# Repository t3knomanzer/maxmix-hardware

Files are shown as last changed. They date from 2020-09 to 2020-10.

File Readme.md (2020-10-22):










## Overview
**Maxmix** is an open-source volume mixer that allows you to control the volume applications from an external custom controller.  
It was originally designed to allow to quickly adjust the volume of a game and an external voice chat application like Discord quckly, but it can do so much more...  
You can find out more about the system in the [project website](https://www.maxmixproject.com).

This repository contains the designs to build the official hardware.

## Contributing
Most files on this repository are binary and do not allow for changes to be merged.  
To prevent changes being overwritten, we  use [LFS with locking](https://github.com/git-lfs/git-lfs/wiki/File-Locking).  

Before you start working on a file, you need to lock it. Locks are exclusive so only one user can lock a file at a time. Locking the file will also make it
writeable locally and allow you to make changes to it.

Here are a few useful commands:

Lock a file
```
$ git lfs lock images/foo.jpg
Locked images/foo.jpg
```

Unlock a file
```
$ git lfs unlock images/foo.jpg
$ git lfs unlock --id=456
```

View locked files
```
$ git lfs locks
images/bar.jpg  jane   ID:123
images/foo.jpg  alice  ID:456
```

Typical workflow
```
$ git lfs lock images/foo.jpg
$ git commit images/foo.jpg -m "My changes"
$ git lfs unlock images/foo.jpg
$ git push
```

## Community
You can join these groups and chats to discuss your-project related questions:

[Website](https://maxmixproject.com)  
[Twitter](https://www.twitter.com/maxmixproject)  
[Reddit](https://www.reddit.com/r/maxmixproject)    
[Discord](https://discord.gg/TmvvgCw)  
[Github](https://www.github.com/t3knomanzer/maxmix-software)  
[Thingiverse](https://www.thingiverse.com/thing:4343186)  
[Prusaprinters](https://www.prusaprinters.org/prints/31336-maxmix)  
[Buy](https://www.amazon.com/dp/B08LMQXTZ3)  
[Donate](https://www.paypal.com/cgi-bin/webscr?cmd=_donations&business=SQS6XJZBCBZA8&currency_code=USD&source=url)

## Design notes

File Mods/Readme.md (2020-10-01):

This folder will contain mods made for the Maxmix device.

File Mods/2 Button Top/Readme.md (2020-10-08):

## Tactile button mod

Uses KY-004 buttons from Ali/Amazon

 - Amazon - https://www.amazon.com/gp/product/B0786BDFT5/ - Soldering
   was poor, needed to be fixed before using.
   
 - Aliexpress - https://www.aliexpress.com/item/4000210666955.html

Use software & firmware located in this folder or source is here - https://github.com/t3knomanzer/maxmix-software/tree/mod-buttons

Currently presses F13 and F14, buttons need to be wired to ground and D10/D11. D8 and D9 are pulled low in this firmware and can be used in place of ground.

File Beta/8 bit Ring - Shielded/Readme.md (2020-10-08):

Shielded LED housing for the project standard 8 bit ring.

Diffuser = Visible, should be printed in a transparent or translucent material. White, Clear, Light Colors...

Shield = Blocks light between cells and from exiting housing, should be printed in a non-translucent material. Black, Dark Colors...

Bracket = Blocks light from exiting bottom and side of housing, should be printed in a non-translucent material. Black, Dark Colors...

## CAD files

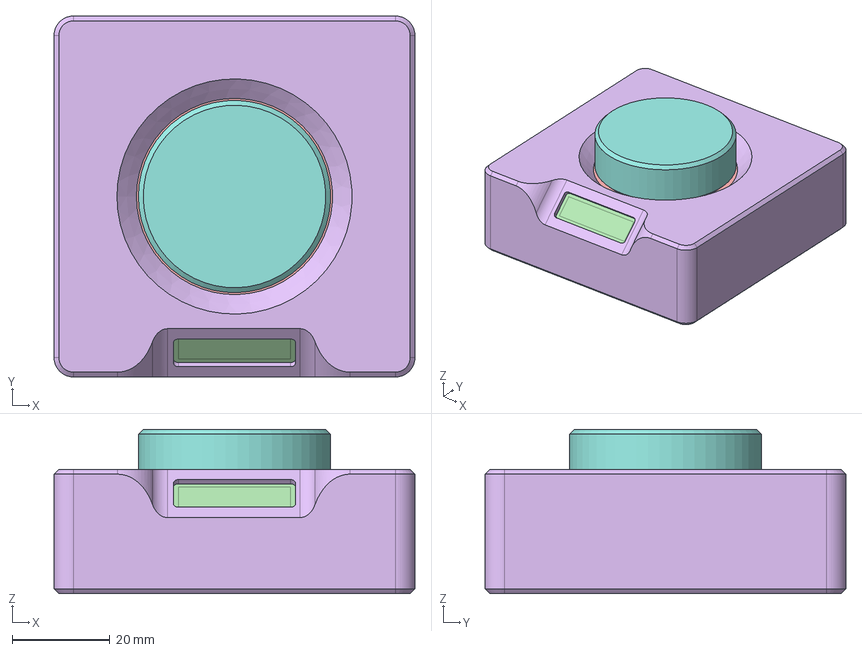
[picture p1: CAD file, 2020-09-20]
Base/R96/Maxmix_Base_R96.step
74.0 x 74.0 x 33.7 mm
Arduino
Rotary
OLED
Top
Bottom
Knob
Tabs
PowerBus
LightRingBracket
LightRing

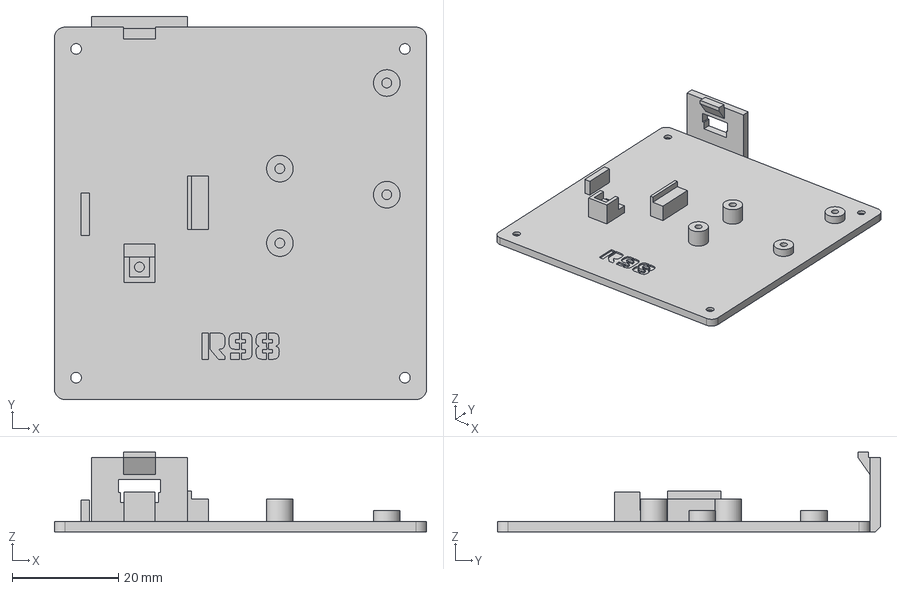
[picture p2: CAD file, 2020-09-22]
Base/R98/Step/Maxmix_Base_Bottom_14mm_R98.step
70.0 x 72.0 x 15.0 mm

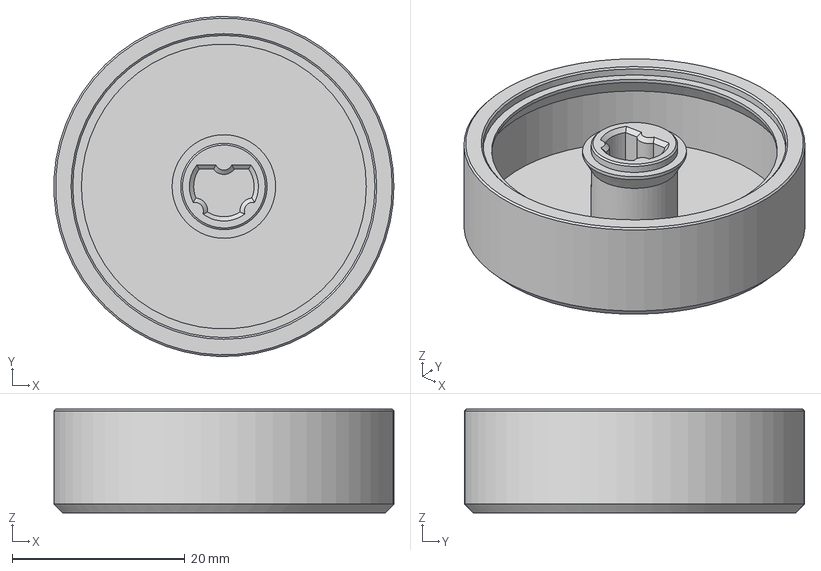
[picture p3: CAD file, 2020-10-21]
Base/R99/Knob/Maxmix_Base_Knob_R99_v6.step
39.4 x 39.4 x 12.0 mm

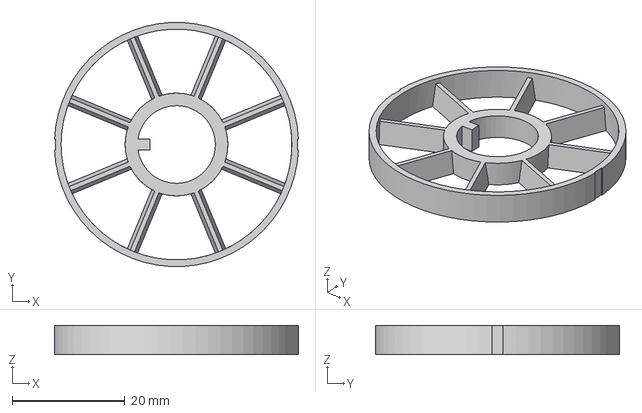
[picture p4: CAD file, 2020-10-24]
Base/R99/LEDAssembly/Maxmix_Base_LEDCells_R99_v3.step
43.4 x 43.3 x 5.20 mm

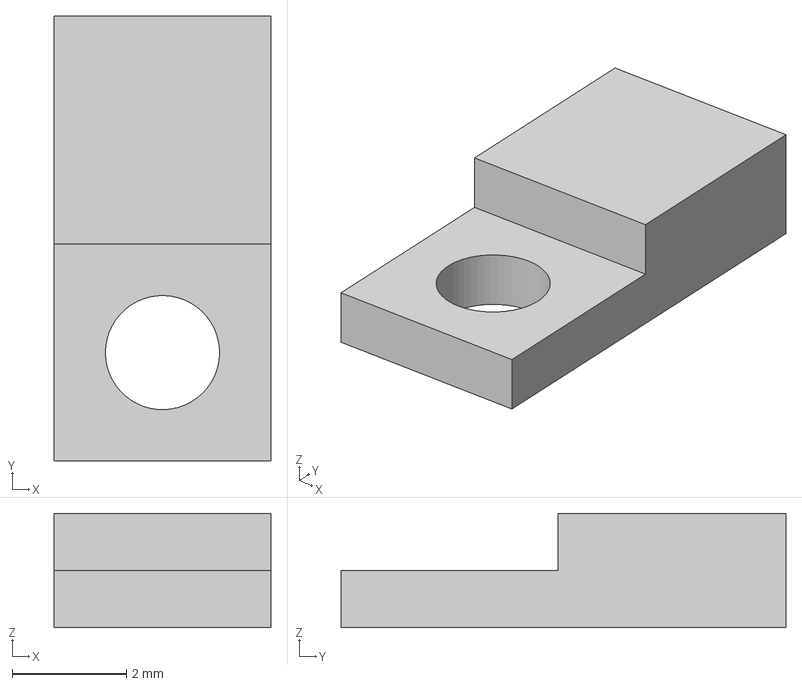
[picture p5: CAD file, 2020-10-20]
Base/R99/Tabs/Maxmix_Base_Tabs_R99_v3.step
3.80 x 7.80 x 2.00 mm

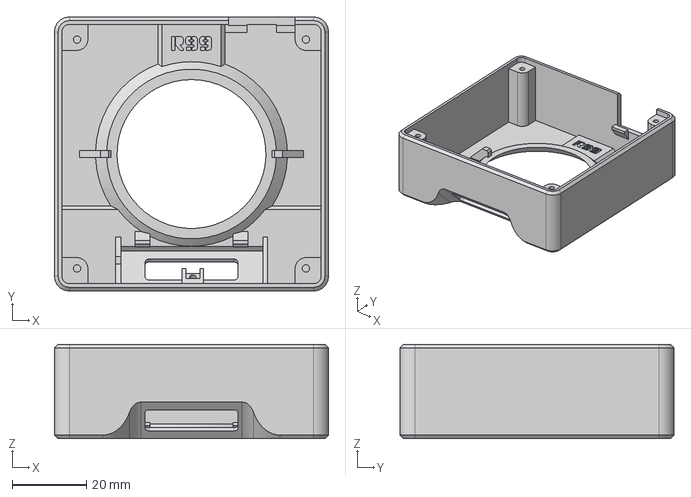
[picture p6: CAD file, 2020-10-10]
Base/R99/Top/Maxmix_Base_Top_R99_v20.step
74.0 x 74.0 x 25.5 mm

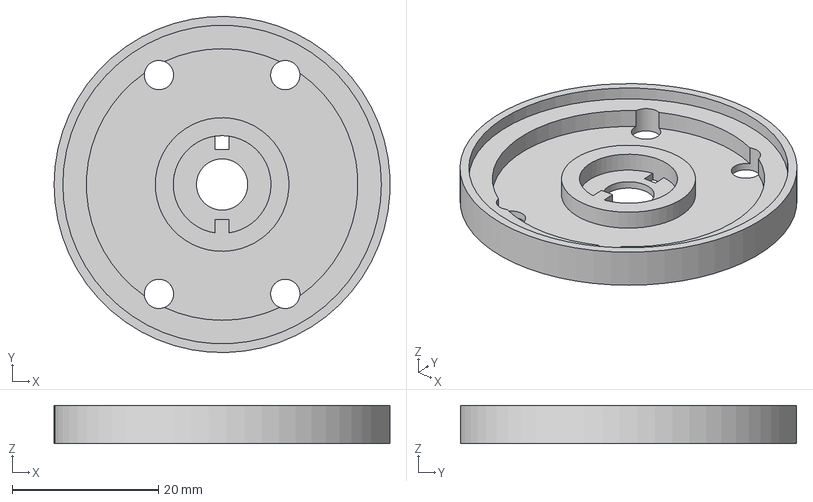
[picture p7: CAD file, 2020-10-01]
Beta/12 bit Ring - Shielded/LED Bracket - Adafruit 12 bit - Shielded v10.step
45.9 x 45.9 x 5.20 mm

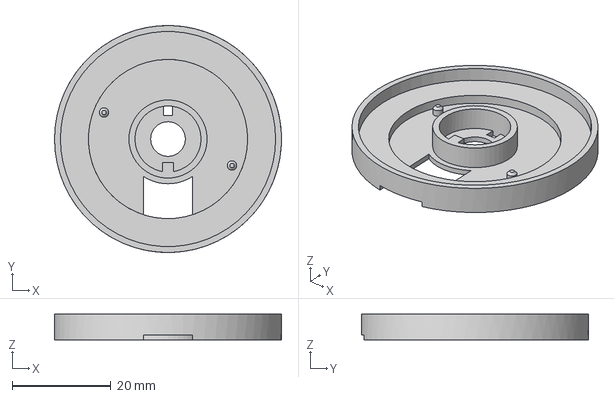
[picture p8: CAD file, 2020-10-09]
Beta/8 bit Ring - Shielded/LED Bracket - 8 bit - ShieldedNoCells.step
45.9 x 45.9 x 5.20 mm

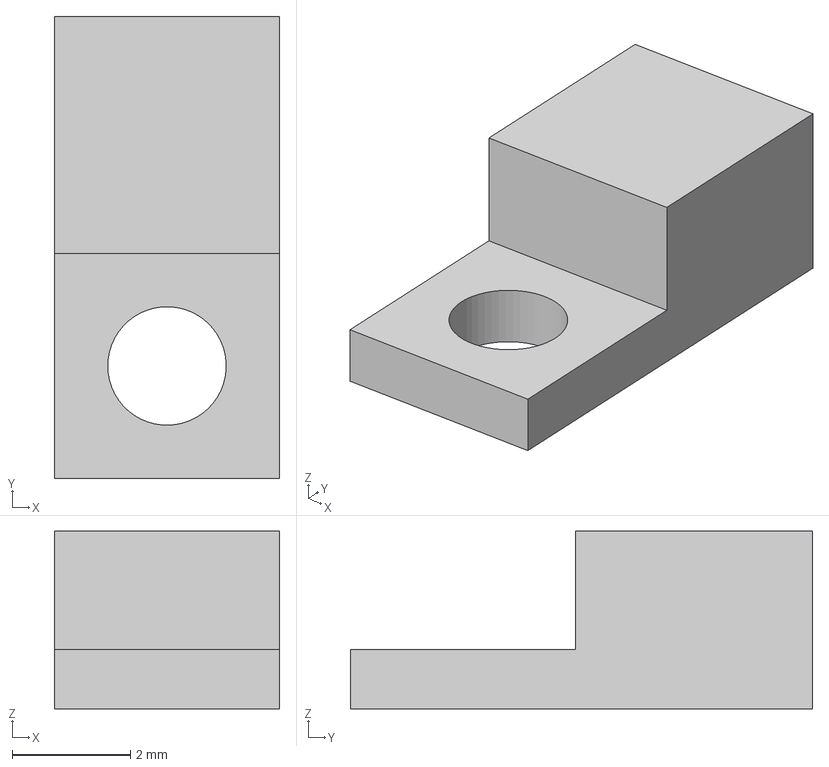
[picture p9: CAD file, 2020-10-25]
Beta/R100/Clamp Tab/Clamp Tab v2.step
3.80 x 7.80 x 3.00 mm

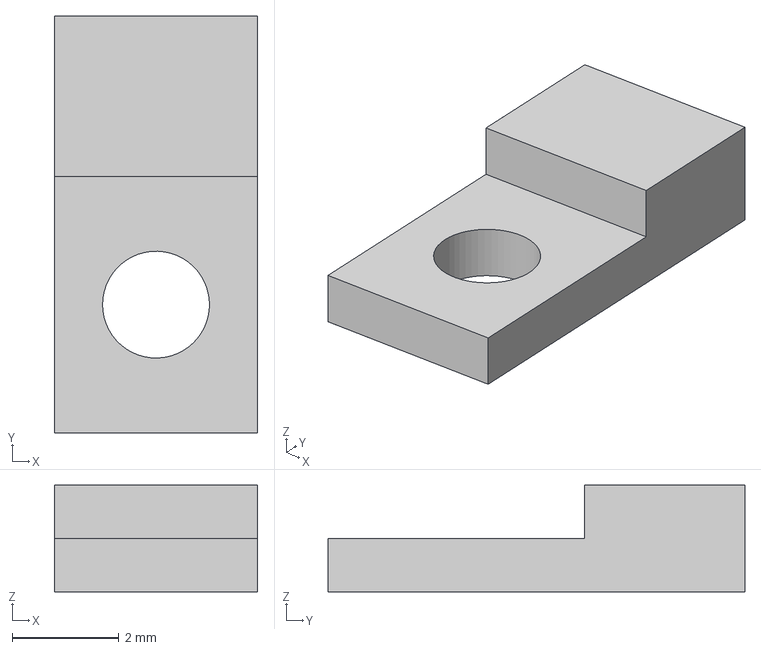
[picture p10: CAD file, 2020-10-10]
Beta/R99/Clamp Tab/Clamp Tab v2.step
3.80 x 7.80 x 2.00 mm

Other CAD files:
Base/R96/Stl/MM_Base_Knob.stl
Base/R97/Maxmix_Base_R97.step
Base/R97/Stl/MM_Base_LightBracket_26mm.stl
Base/R98/Stl/MM_Base_Diffuser_R98.stl
Base/R99/Bottom/Maxmix_Base_Bottom_14mm_R99_v40.step
Beta/R100/Bottom/Bottom - 17mm Encoder v4.step
Beta/R100/LED Diffuser R100 - 8 bit - Shielded - Gap 0 v3.stl
Beta/R100/Top/Top v2.step
Base/R96/MaxMix_Base_R96.f3d
Base/R96/Stl/MM_Base_Bottom.stl
Base/R96/Stl/MM_Base_LightBracket_28mm.stl
Base/R96/Stl/MM_Base_Top.stl
Base/R96/Stl/MM_Base_TopCap.stl
Base/R97/MaxMix_Base_R97.f3d
Base/R97/Stl/MM_Base_Top.stl
Base/R98/Maxmix_Base_Bottom_R98.f3d
Base/R98/Maxmix_Base_Diffuser_R98.f3d
Base/R98/Maxmix_Base_Knob_R98.f3d
Base/R98/Maxmix_Base_LEDBracket_R98.f3d
Base/R98/Maxmix_Base_Tabs_R98.f3d
Base/R98/Maxmix_Base_Top_R98.f3d
Base/R98/Step/Maxmix_Base_Bottom_17mm_R98.step
Base/R98/Step/Maxmix_Base_Diffuser_R98.step
Base/R98/Step/Maxmix_Base_Knob_R98.step
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

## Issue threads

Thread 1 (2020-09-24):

Thin case above Arduino and Power Bus

limited660, 2020-09-24:
**Guidelines**
- [X] I have reviewed the [guidelines for contributing](https://github.com/t3knomanzer/maxmix-software/blob/master/.github/CONTRIBUTING.md) to this repository.

**Is your feature request related to a problem? Please describe.**
Not enough room for stacked wires above.

**Describe the solution you'd like**
Thin the top case above Arduino and Power Bus to allow stacked wires.

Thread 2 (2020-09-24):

Add provisions for second power bus

limited660, 2020-09-24:
**Guidelines**
- [X] I have reviewed the [guidelines for contributing](https://github.com/t3knomanzer/maxmix-software/blob/master/.github/CONTRIBUTING.md) to this repository.

**Is your feature request related to a problem? Please describe.**
Running out of power and ground connections.

**Describe the solution you'd like**
Add second power bus mounting location for additional connections.

**Describe alternatives you've considered**
Custom ganged jumpers, soldering, wire wrapping.

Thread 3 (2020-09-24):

LED bracket shield

limited660, 2020-09-24:
**Guidelines**
- [X] I have reviewed the [guidelines for contributing](https://github.com/t3knomanzer/maxmix-software/blob/master/.github/CONTRIBUTING.md) to this repository.

**Is your feature request related to a problem? Please describe.**
Light bleed into case from LED ring

**Describe the solution you'd like**
Shield around LED ring to block light spill.

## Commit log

2019-08-17 Adding gitignore
    [Base_Bottom.stl, Base_Top.stl, Base_Top_Cap.stl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]
2020-05-07 Updating 3mf and gcode to use the latest stl files and version of Slic3r.
    [MM_Plate_0.2mm_Prusament_PLA.3mf, MM_Plate_0.2mm_Prusament_PLA.zip.amf]
2020-05-13 Adding .stl with all pieces together.
    [All.stl]
2020-05-20 Added power bus, updated font and increased height.
    [Base_Bottom.stl, Base_Top.stl, Base_Top_Cap.stl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]
2020-05-22 Removing spacer from top cap.
    [Base_Bottom.stl, Base_Top.stl, Base_Top_Cap.stl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]
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2020-05-23 Adding top cap spacer back and increasing version.
    [Base_Bottom.stl, Base_Top.stl, Base_Top_Cap.stl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]
2020-05-25 Added light ring.
    [All.stl, Base_Bottom.stl, Base_Top.stl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]
2020-05-26 Updating 3mf project files with latest stl.
    [MM_Base_TopCap_0.2mm_Prusament_PLA.3mf]
2020-05-27 Reducing knob height
    [MM_Base_Knob.stl]
2020-05-27 Updating project files with new button
    [MM_Base_Plate_0.2mm_Prusament_PLA.3mf]
2020-05-27 Creating split stl files for manufacturing quoting
    [MM_Base_All.stl, MM_Base_All_ColorA.stl, MM_Base_All_ColorB.stl]
2020-06-08 Consolidating project files
    [MM_Base_ColorA_0.2mm_Prusament_PLA.3mf, MM_Base_ColorB_0.2mm_Prusament_PLA.3mf, MM_Base_Knob_0.2mm_Prusament_PLA.3mf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]
2020-06-09 Removing all files before moving to LFS
    [MM_Base_All.stl, MM_Base_All_ColorA.stl, MM_Base_All_ColorB.stl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]
2020-06-09 Adding LFS files
    [MM_Base_All.stl, MM_Base_All_ColorA.stl, MM_Base_All_ColorB.stl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]
2020-06-16 Re-organizing files
    [MM_Base_All.stl, MM_Base_Bottom.stl, MM_Base_ColorA.stl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]
2020-06-16 Adding master fusion file for v0.95
    [MaxMix_Base_fv300_hv095.f3d]
2020-06-16 Reorganizing print and order files
    [MM_Base_Bottom.stl, MM_Base_Knob.stl, MM_Base_Knob_0.2mm_Prusament_PLA.3mf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]
2020-07-08 Updating version to R96 and re-exporting everything
    [MM_Base_All.stl, MM_Base_All_0.2mm_Prusament_PLA.3mf, MM_Base_Bottom.stl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]
2020-09-20 Preparing for public release
    [MM_Base_All.stl, MM_Base_All_0.2mm_Prusament_PLA.3mf, MM_Base_Bottom.stl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]
2020-09-22 Reorganizing and exporting step files
    [MM_Base_Bottom.stl, MM_Base_Bottom_14mm.stl, MM_Base_Bottom_17mm.stl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]
2020-09-22 Adding R98 suffix to files
    [MM_Base_Bottom_14mm_R98.stl, MM_Base_Bottom_17mm_R98.stl, MM_Base_Knob_R98.stl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]
2020-09-23 Adding missing R98 diffuser stl
    [Maxmix_Base_Diffuser_R98.stl]
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2020-09-29 Initial commit of button top
    Good release of button top, tested already.
    [Top Tactile Clean v9.f3d, Top Tactile Clean v9.step, Top Tactile Clean v9.stl]
2020-10-01 12 bit Ring Assembly
    Uses Adafruit 1643 12 x 500 ring - https://www.adafruit.com/product/1643
    [LED Bracket - Adafruit 12 bit - Shielded v9.f3d, LED Bracket - Adafruit 12 bit - Shielded v9.step, LED Bracket - Adafruit 12 bit - Shielded v9.stl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]
2020-10-01 Center Change
    Changed diameter in center ring
    [LED Bracket - Adafruit 12 bit - Shielded v10.f3d, LED Bracket - Adafruit 12 bit - Shielded v10.step, LED Bracket - Adafruit 12 bit - Shielded v10.stl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]
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2020-10-08 8 bit shield & cleanup
    Added 8 bit shield and folder split for beta versus mods
    [LED Bracket - 8 bit - Shielded v1.f3d, LED Bracket - 8 bit - Shielded v1.step, LED Bracket - 8 bit - Shielded v1.stl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]
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2020-10-09 Adding knob with cap
    [Knob - Closed v12.f3d, Knob - Closed.f3d, Knob - Closed.stl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]
2020-10-09 Adding led bracked shield without cells
    [LED Bracket - 8 bit - ShieldedNoCells.f3d, LED Bracket - 8 bit - ShieldedNoCells.step, LED Bracket - 8 bit - ShieldedNoCells.stl]
2020-10-10 Top Update
    Thinned top above Arduino and Power Bus by 1mm
    [Top v20.f3d, Top v20.step, Top v20.stl]
2020-10-10 Bottom Updates
    Added R99 bottom, 17mm encoder mounting moved to center per T3Ks findings.
    Outside Arduino guide moved to allow easier installation.
    Removed USB C variant due to Nano crashing issues.
    [Bottom - 14mm Encoder v37.stl, Bottom - 17mm Encoder v37.stl, Bottom v37.f3d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]
2020-10-10 Tab Update
    Combined TabMCU and TabScreen into one tab.
    [Clamp Tab v2.f3d, Clamp Tab v2.step, Clamp Tab v2.stl]
2020-10-10 Diffuser Updates
    Rotated keys to allow front or back 0 on LED ring.
    Gap 0 means the gap between LEDs will be aligned with center of Maxmix.
    [Bottom - 14mm Encoder v37.stl, Bottom - 17mm Encoder v37.stl, Clamp Tab v2.stl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]
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2020-10-10 Tolerance Adjusting
    [LED Bracket - 8 bit - Shielded - Cells - Gap 0 v6.f3d, LED Bracket - 8 bit - Shielded - Cells - Gap 0 v6.stl, LED Bracket - 8 bit - Shielded - Cells - Gap 0 v7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]
2020-10-10 Updated LED assemblies
    Cells can be added or removed for desired effect.
    [LED Bracket - 8 bit - Shielded - Cells - Gap 0 v7.f3d, LED Bracket - 8 bit - Shielded - Cells - Gap 0 v7.step, LED Bracket - 8 bit - Shielded - Cells - Gap 0 v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]
2020-10-10 Knob & Cap
    Added knob and light blocking cap
    [Cap v2.f3d, Cap v2.step, Cap v2.stl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]
2020-10-10 Knob update
    Changed size of cap support
    [Knob v4.f3d, Knob v4.stl, Knob v5.f3d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]
2020-10-10 Removing chamfers from bottom of the knob
    [Knob v6.f3d, Knob v6.step, Knob v6.stl]
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2020-10-11 Encoder updates
    Added PCB hold down to non-screw side, fixed positioning on 17mm encoder mount.
    [Bottom - 14mm Encoder v37.stl, Bottom - 14mm Encoder v40.step, Bottom - 14mm Encoder v40.stl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]
2020-10-17 Deleting temporary knob files
    [Knob - Closed v12.f3d, Knob - Closed.f3d, Knob - Closed.stl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]
2020-10-20 Hole position fixed
    Fixed hole position on clamp tab for use on MCU.
    [Clamp Tab v2.f3d, Clamp Tab v2.stl, Clamp Tab v3.f3d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]
2020-10-21 Changed knob to use ribs
    Changed mounting method to crush ribs instead of a tight fit on the d shaft.
    [Knob v5.f3d, Knob v5.step, Knob v5.stl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]
2020-10-24 Change diameter of through hole for easier assembly
    [LED Cells - 8 bit - Gap 0 v5.f3d, LED Cells - 8 bit - Gap 0 v5.stl, LED Cells - 8 bit - Gap 0 v6.f3d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]
2020-10-25 R100 Start
    Adjusted depths of holes to prevent screw pushing material below encoder, power bus, and OLED clamp.
    [Bottom - 14mm Encoder v4.f3d, Bottom - 14mm Encoder v4.step, Bottom - 14mm Encoder v4.stl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]
2020-10-26 Moving R99 to Release
    [LED Bracket - 8 bit - Shielded - Gap 0 v3.f3d, LED Bracket - 8 bit - Shielded - Gap 0 v3.step, LED Bracket - 8 bit - Shielded - Gap 0 v3.stl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]
